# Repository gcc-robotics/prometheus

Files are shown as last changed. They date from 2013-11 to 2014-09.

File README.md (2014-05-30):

Prometheus
==========

The Prometheus is a robotic arm project created by the [Glendale Community College Robotics Academy][0].

This repository contains the software, electronics schematics, and mechanical models for the Prometheus robotic arm.

Prometheus Startup Procedure
----------------------------
1. Make sure the hardware and electronics are connected correctly.
2. Power up the Raspberry Pi, Router, and only the 5V rail for the electronics board.
   __Do not turn on the 12V rail! This will cause the arm to move to it's default position which could cause rapid movement and the arm could impact something.__
3. Connect a computer, tablet, or phone to the router either by ethernet or WiFi. The WiFi info is on the router.
4. Now open a browser and go to:

		10.33.0.2
	
	 This will open up the Prometheus Remote Control Interface.

5. Now click __Settings__ in the top right corner of the screen and then turn on the __Command Console__. Click the __X__ in the top right corner to close the Settings Screen.

6. Now go to the bottom of the page and tun the following commands:

        getJointLimits 0
        getJointLimits 1
        getJointLimits 2
        getJointLimits 3
        getJointLimits 4

7. Now use the setpoint sliders to set all the joint to a position where the arm will not hit anything when it is turned on.

8. Finaly, once you are confident that the setpoints are good turn on the 12V rail. The arm will now move to the setpoints you specified and you will be able to control it using the remote control interface.

Sistine Chapel - Arduino Software
---------------------------------

The __sistineChapel__ subdirectory contains the Arduino software for controlling the Prometheus.

### Setup

To compile and upload to the Arduino use the free [Arduino IDE][1]. Once you have installed the IDE the following steps will let you upload and test the Arduino software.

* Start Arduino IDE
* Select Tools -> Board -> Arduino Pro Mini 5V W/ ATmega328
* Open [sistineChapel/sistineChapel.ino][2] 
* File -> Upload

Narthex - Raspberry Pi Software
-------------------------------

The __narthex__ subdirectory contains the software to be run on the Raspberry Pi. 

The software runs a simple web server to serve a static web page with controls for Prometheus enabling remote control. The python code transfers commands between the Arduino and the Javascript running in the open webpage.

[0]: http://www.robotics.glendale.edu
[1]: http://arduino.cc/en/Main/Software
[2]: https://github.com/gcc-robotics/prometheus/blob/master/sistineChapel/sistineChapel.ino

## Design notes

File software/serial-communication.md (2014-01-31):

Serial Communication Documentation
==================================

This is a list of commands that the Arduino will accept over serial. The commands should be sent as strings with a newline character at the end.

Status Reporting
----------------

The Arduino sends the current angle for every joint in every loop iteration with the following syntax:

armStatus [joint0angle] [joint1angle] [joint2angle] [joint3angle] [joint4angle] [joint0error] [joint1error] [joint2error] [joint3error] [joint4error]

* joint[0-4]angle
  Float between 0.0 and 360.0
* joint[0-4]error
  Float between 0.0 and 360.0

Commands
--------

* setJointAngle [jointNumber] [angle]
* getJointAngle [jointNumber]
* getJointLimits [jointNumber]
* setJointGains [jointNumber] [PGain] [IGain] [DGain]
* getJointGains [jointNumber]
* getjointError [jointNumber]

### setJointAngle [jointNumber] [angle]

#### Description

The Arduino sets the selected joint to the provided angle.

#### Params

* jointNumber
  Integer between 0 and 4
* angle
  Integer between 0 and 359

#### Response

jointSetPoint [jointNumber] [angle]

* jointNumber
  Integer between 0 and 4
* angle
  Integer between 0 and 359

### getJointAngle [jointNumber]

#### Description

The Arduino gets the current encoder angle for the provided joint and sends it back in the response.

#### Params

* jointNumber
  Integer between 0 and 4

#### Response

jointAngle [jointNumber] [angle]

* jointNumber
  Integer between 0 and 4
* angle
  Integer between 0 and 359

### getJointLimits [jointNumber]

#### Description

The Arduino gets the current encoder angle for the provided joint and sends it back in the response.

#### Params

* jointNumber
  Integer between 0 and 4

#### Response

jointLimits [jointNumber] [min] [max]

* jointNumber
  Integer between 0 and 4
* min
  Integer between 0 and 359
* max
  Integer between 0 and 359

### getJointGains [jointNumber]

#### Description

The Arduino will return the PID gains for the current joint.

#### Params

* jointNumber
  Integer between 0 and 4

#### Response

jointGains [jointNumber] [PGain] [IGain] [DGain]

* jointNumber
  Integer between 0 and 4
* PGain
  Float between 0.0 and 5.0
* IGain
  Float between 0.0 and 5.0
* DGain
  Float between 0.0 and 5.0

### setJointGains [jointNumber] [PGain] [IGain] [DGain]

#### Description

The Arduino will set the provided values as the joint PID gains.

#### Params

* jointNumber
  Integer between 0 and 4
* PGain
  Float between 0.0 and 5.0 and must always be 2 digits after the decimal place
* IGain
  Float between 0.0 and 5.0 and must always be 2 digits after the decimal place
* DGain
  Float between 0.0 and 5.0 and must always be 2 digits after the decimal place

#### Response

No response

### getJointError [jointNumber]

#### Description

The Arduino will return the current angle error for the provided joint.

#### Params

* jointNumber
  Integer between 0 and 4

#### Response

jointError [jointNumber] [error]

* jointNumber
  Integer between 0 and 4
* error
  Float between -180.0 and 180.0

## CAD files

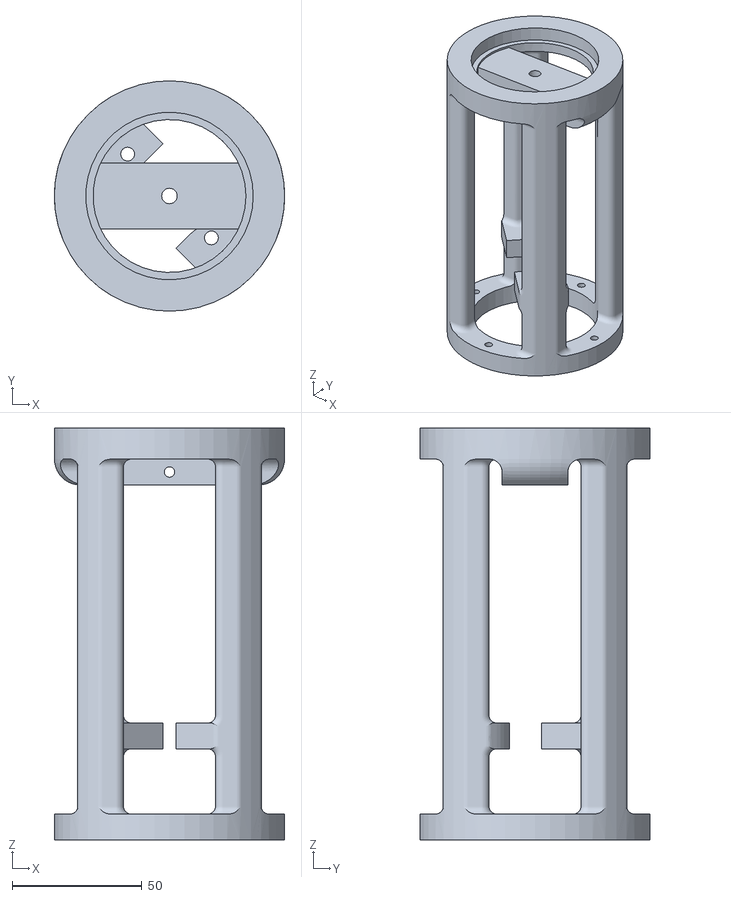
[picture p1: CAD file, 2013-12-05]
mechanical/forearm-front.stl
88.9 x 88.9 x 159.0

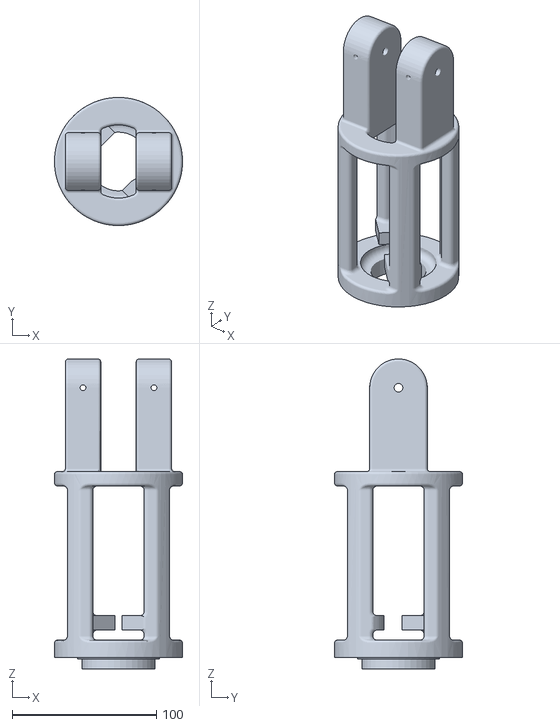
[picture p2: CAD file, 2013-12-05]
mechanical/forearm-back.stl
88.9 x 88.9 x 215.1

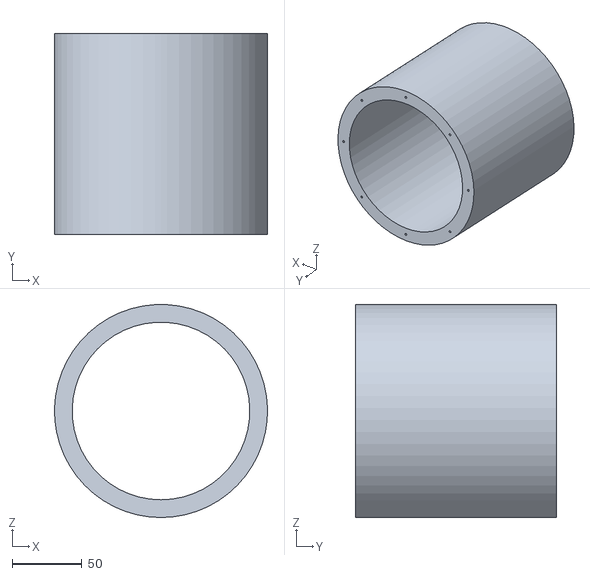
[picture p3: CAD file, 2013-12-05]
mechanical/base.stl
152.3 x 143.6 x 152.4

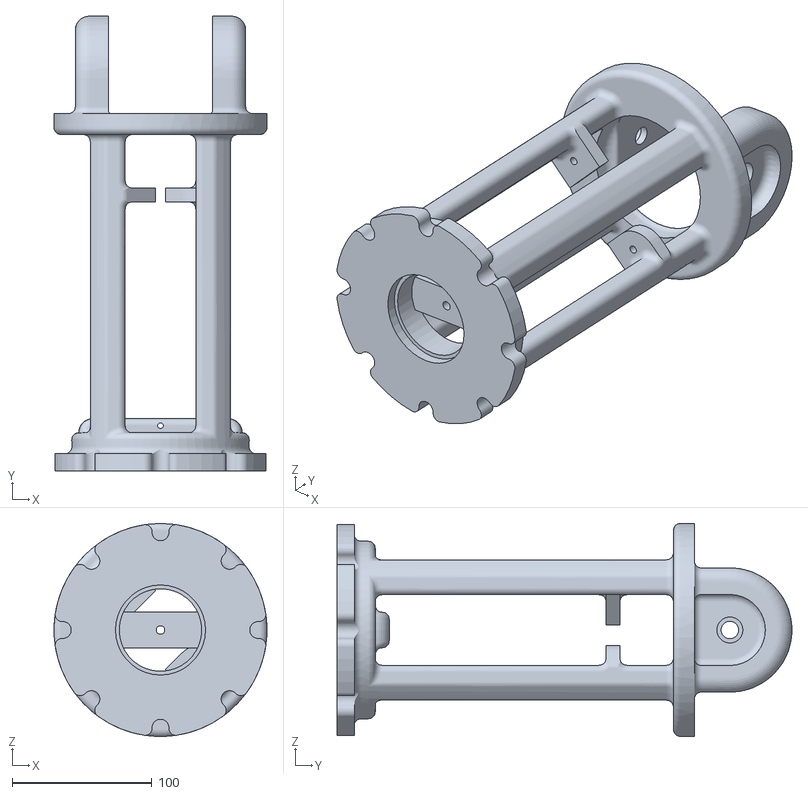
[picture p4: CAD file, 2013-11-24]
mechanical/torso.stl
152.4 x 325.5 x 152.4

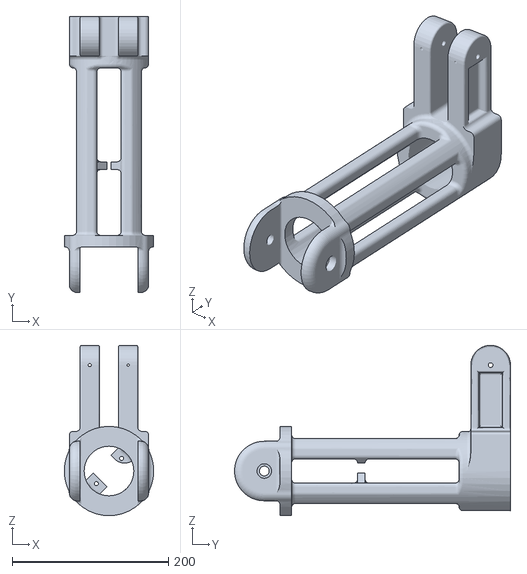
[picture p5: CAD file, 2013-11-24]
mechanical/humerus.stl
114.3 x 353.0 x 217.9

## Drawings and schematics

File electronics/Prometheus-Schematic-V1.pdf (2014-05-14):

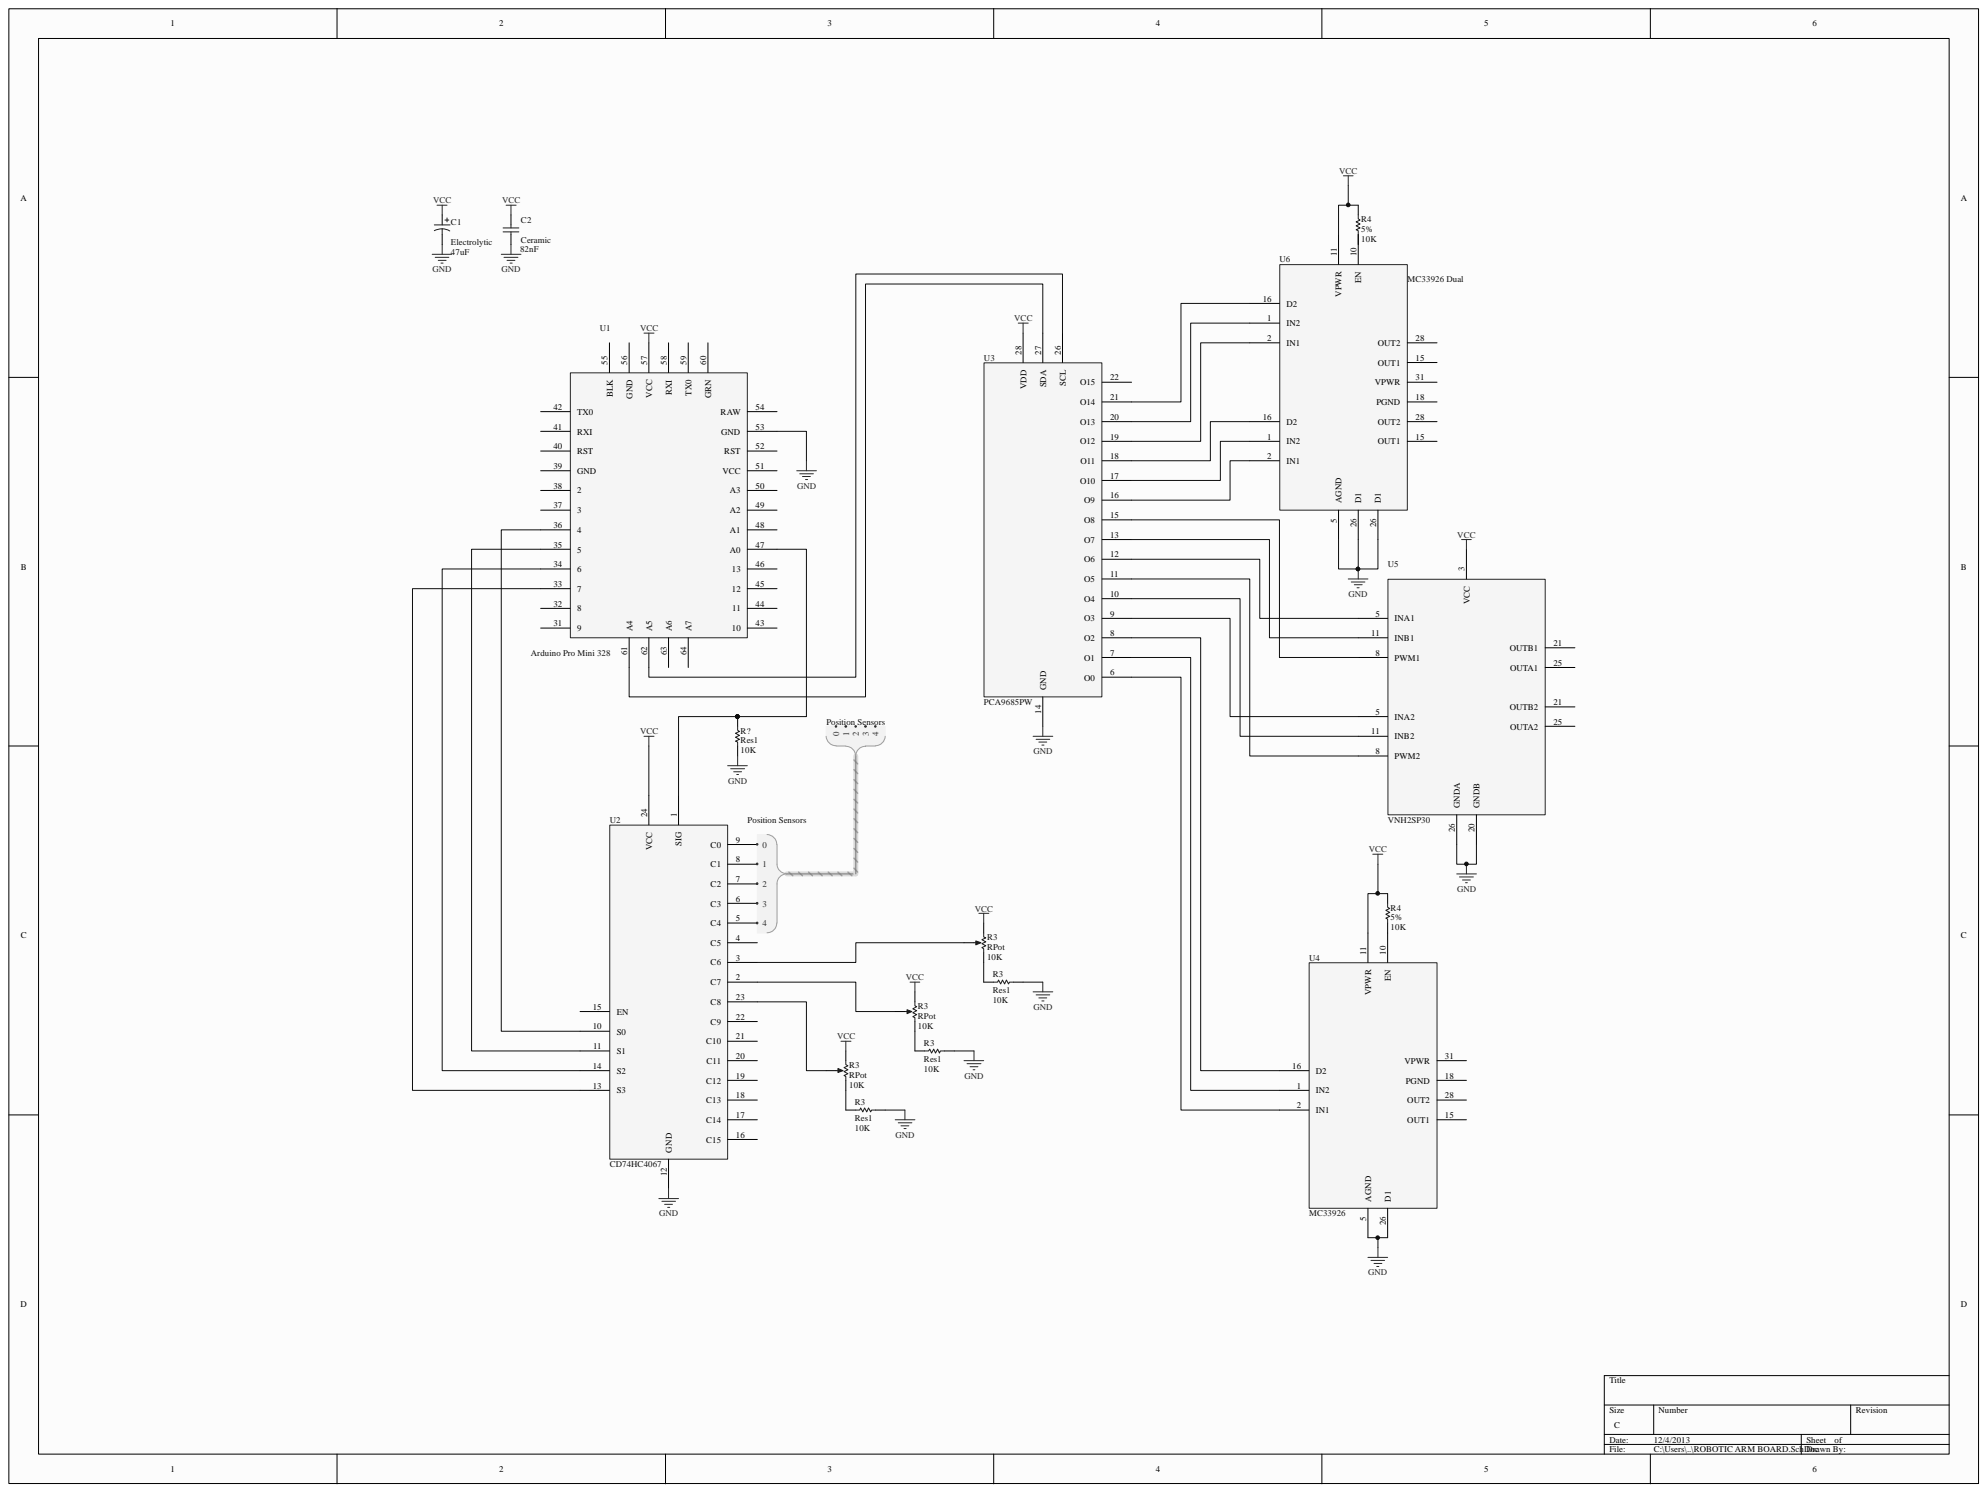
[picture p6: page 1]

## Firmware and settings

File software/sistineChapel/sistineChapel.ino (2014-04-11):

#include <Wire.h>
#include <Adafruit_PWMServoDriver.h>

#include "robotArm.h"
#include "debugger.h"
#include "commandProcessor.h"

// This isn't the greatest placement
RobotArm arm = RobotArm();
Debugger debug = Debugger();
CommandProcessor commandProcessor = CommandProcessor();

// Enable or disable debugger
boolean runDebugger = false;

void setup() 
{ 
	// Start serial communication at the specified baud rate
	Serial.begin(115200); // 115200 is max

	// Set timeout for serial read functions to 10ms
	// Use 10ms instead of the default 1000 so that the
	// arm controls work better while the debugger is active
	Serial.setTimeout(50);

	// Setup the arm
	arm.setup();
	commandProcessor.setup(&arm);
	debug.setup(arm.getMultiplexer(), arm.getMotorController(), &arm);

	// Interrupt
	attachInterrupt(arm.interruptNumber, globalInterruptResponder, CHANGE);

	// Set a random setPoint for the elbow
	//randomSeed(analogRead(A3));
	//arm.waist(random(0, 360));
}

void loop() 
{
	arm.loop();
	commandProcessor.loop();

	if(runDebugger)
	{
		debug.loop();
	}

	/*int pin = 1;
	Serial.println(analogRead(pin));*/
}

void globalInterruptResponder()
{
	arm.interruptResponder();
}

float stringToFloat(String input)
{
	int dotPosition = input.indexOf(".");
	int decimalPlaces = input.length() - (dotPosition + 1);

	int first = input.substring(0, dotPosition).toInt();
	int second = input.substring(dotPosition + 1).toInt();

	return first + (second / pow(10, decimalPlaces));
}

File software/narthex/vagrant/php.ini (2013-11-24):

[PHP]

;;;;;;;;;;;;;;;;;;;
; About php.ini   ;
;;;;;;;;;;;;;;;;;;;
; PHP's initialization file, generally called php.ini, is responsible for
; configuring many of the aspects of PHP's behavior.

; PHP attempts to find and load this configuration from a number of locations.
; The following is a summary of its search order:
; 1. SAPI module specific location.
; 2. The PHPRC environment variable. (As of PHP 5.2.0)
; 3. A number of predefined registry keys on Windows (As of PHP 5.2.0)
; 4. Current working directory (except CLI)
; 5. The web server's directory (for SAPI modules), or directory of PHP
; (otherwise in Windows)
; 6. The directory from the --with-config-file-path compile time option, or the
; Windows directory (C:\windows or C:\winnt)
; See the PHP docs for more specific information.
; http://php.net/configuration.file

; The syntax of the file is extremely simple.  Whitespace and Lines
; beginning with a semicolon are silently ignored (as you probably guessed).
; Section headers (e.g. [Foo]) are also silently ignored, even though
; they might mean something in the future.

; Directives following the section heading [PATH=/www/mysite] only
; apply to PHP files in the /www/mysite directory.  Directives
; following the section heading [HOST=www.example.com] only apply to
; PHP files served from www.example.com.  Directives set in these
; special sections cannot be overridden by user-defined INI files or
; at runtime. Currently, [PATH=] and [HOST=] sections only work under
; CGI/FastCGI.
; http://php.net/ini.sections

; Directives are specified using the following syntax:
; directive = value
; Directive names are *case sensitive* - foo=bar is different from FOO=bar.
; Directives are variables used to configure PHP or PHP extensions.
; There is no name validation.  If PHP can't find an expected
; directive because it is not set or is mistyped, a default value will be used.

; The value can be a string, a number, a PHP constant (e.g. E_ALL or M_PI), one
; of the INI constants (On, Off, True, False, Yes, No and None) or an expression
; (e.g. E_ALL & ~E_NOTICE), a quoted string ("bar"), or a reference to a
; previously set variable or directive (e.g. ${foo})

; Expressions in the INI file are limited to bitwise operators and parentheses:
; |  bitwise OR
; ^  bitwise XOR
; &  bitwise AND
; ~  bitwise NOT
; !  boolean NOT

; Boolean flags can be turned on using the values 1, On, True or Yes.
; They can be turned off using the values 0, Off, False or No.

; An empty string can be denoted by simply not writing anything after the equal
; sign, or by using the None keyword:

;  foo =         ; sets foo to an empty string
;  foo = None    ; sets foo to an empty string
;  foo = "None"  ; sets foo to the string 'None'

; If you use constants in your value, and these constants belong to a
; dynamically loaded extension (either a PHP extension or a Zend extension),
; you may only use these constants *after* the line that loads the extension.

;;;;;;;;;;;;;;;;;;;
; About this file ;
;;;;;;;;;;;;;;;;;;;
; PHP comes packaged with two INI files. One that is recommended to be used
; in production environments and one that is recommended to be used in
; development environments.

; php.ini-production contains settings which hold security, performance and
; best practices at its core. But please be aware, these settings may break
; compatibility with older or less security conscience applications. We
; recommending using the production ini in production and testing environments.

; php.ini-development is very similar to its production variant, except it's
; much more verbose when it comes to errors. We recommending using the
; development version only in development environments as errors shown to
; application users can inadvertently leak otherwise secure information.

;;;;;;;;;;;;;;;;;;;
; Quick Reference ;
;;;;;;;;;;;;;;;;;;;
; The following are all the settings which are different in either the production
; or development versions of the INIs with respect to PHP's default behavior.
; Please see the actual settings later in the document for more details as to why
; we recommend these changes in PHP's behavior.

; allow_call_time_pass_reference
;   Default Value: On
;   Development Value: Off
;   Production Value: Off

; display_errors
;   Default Value: On
;   Development Value: On
;   Production Value: Off

; display_startup_errors
;   Default Value: Off
;   Development Value: On
;   Production Value: Off

; error_reporting
;   Default Value: E_ALL & ~E_NOTICE
;   Development Value: E_ALL | E_STRICT
;   Production Value: E_ALL & ~E_DEPRECATED

; html_errors
;   Default Value: On
;   Development Value: On
;   Production value: Off

; log_errors
;   Default Value: Off
;   Development Value: On
;   Production Value: On

; magic_quotes_gpc
;   Default Value: On
;   Development Value: Off
;   Production Value: Off
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

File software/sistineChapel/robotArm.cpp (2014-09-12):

#import <Arduino.h>
#include <math.h>
#include "robotArm.h"

RobotArm::RobotArm()
{
	/*	Joint numbers:
		0: waist
		1: shoulder
		2: elbow
		3: wrist
		4: hand
	*/
}

void RobotArm::setup()
{
	const int numMotors = 5;
	this->openClawPin = 9;
	this->closeClawPin = 8;

	pinMode(this->openClawPin, OUTPUT);
	pinMode(this->closeClawPin, OUTPUT);
	
	// Motor numbers
	this->motorNumber[0] = 0;
	this->motorNumber[1] = 1;
	this->motorNumber[2] = 2;
	this->motorNumber[3] = 3;
	this->motorNumber[4] = 4;

	// Encoder numbers
	this->encoderNumber[0] = 0;
	this->encoderNumber[1] = 1;
	this->encoderNumber[2] = 2;
	this->encoderNumber[3] = 3;
	this->encoderNumber[4] = 4;

	// Encoder offsets
	this->encoderOffset[0] = 135;
	this->encoderOffset[1] = 34.0;
	this->encoderOffset[2] = 292.0;
	this->encoderOffset[3] = 113.0;
	this->encoderOffset[4] = 0;

	// Interrupt 
	this->emergencyState = false;
	this->interruptNumber = 1;
	this->interruptPinNumber = 3;

	pinMode(this->interruptPinNumber, INPUT);

	// Create and setup member objects
	this->mux = Multiplexer();
	this->motor = MotorController();
	this->motorSpeed = PIMotorSpeed();

	this->motor.setup();
}

void RobotArm::interruptResponder()
{
	// Get the state of the interrupt pin
	this->emergencyState = digitalRead(this->interruptPinNumber);
}

Multiplexer* RobotArm::getMultiplexer()
{
	return &(this->mux);
}

MotorController* RobotArm::getMotorController()
{
	return &(this->motor);
}

PIMotorSpeed* RobotArm::getPIMotorSpeed()
{
	return &(this->motorSpeed);
}

bool RobotArm::moveJointToSetPoint(int jointNumber)
{
	// Get the current angle
	float currentAngle = this->getJointAngle(jointNumber);

	// Serial.print("Moving Joint: ");
	// Serial.print(jointNumber);

	// Serial.print(", Curent angle: ");
	// Serial.print(currentAngle);

	// Get the motor speed
	int motorSpeed = this->motorSpeed.calculate(jointNumber, currentAngle);

	// Serial.print(", Calculated motor speed: ");
	// Serial.println(motorSpeed);

	this->motor.speed(jointNumber, motorSpeed);
}

void RobotArm::setJointAngle(int jointNumber, float angle)
{
	this->motorSpeed.setSetPoint(jointNumber, angle);
}

float RobotArm::getJointAngle(int jointNumber)
{
	float encoderOutput = this->mux.readEncoder(this->encoderNumber[jointNumber]) - encoderOffset[jointNumber];
	
	while(encoderOutput < 0)
	{
		encoderOutput += 360;
	}
	
	return encoderOutput;
}

float RobotArm::getJointMinimum(int jointNumber)
{
	return this->motorSpeed.getJointMin(jointNumber);
}

float RobotArm::getJointMaximum(int jointNumber)
{
	return this->motorSpeed.getJointMax(jointNumber);
}

void RobotArm::openClaw()
{
	digitalWrite(this->openClawPin, HIGH);
	digitalWrite(this->closeClawPin, LOW);
}

void RobotArm::closeClaw()
{
	digitalWrite(this->openClawPin, LOW);
	digitalWrite(this->closeClawPin, HIGH);
}

void RobotArm::brakeClaw()
{
	digitalWrite(this->openClawPin, LOW);
	digitalWrite(this->closeClawPin, LOW);
}

void RobotArm::waist(float targetAngle)
{
	this->setJointAngle(0, targetAngle);
}

void RobotArm::shoulder(float targetAngle)
{
	this->setJointAngle(1, targetAngle);
}

void RobotArm::elbow(float targetAngle)
{
	this->setJointAngle(2, targetAngle);
}

void RobotArm::wrist(float targetAngle)
{
	this->setJointAngle(3, targetAngle);
}

void RobotArm::hand(float targetAngle)
{
	this->setJointAngle(4, targetAngle);
}

void RobotArm::loop()
{
	if(!this->emergencyState)
	{
		// Waist
		this->moveJointToSetPoint(0);

		// Shoulder
		this->moveJointToSetPoint(1);

		// Elbow
		this->moveJointToSetPoint(2);

		// Wrist
		this->moveJointToSetPoint(3);

		// Hand
		this->moveJointToSetPoint(4);
	}
	else
	{
		// Emergency State is Active!
		// Coast for now, brake when we have fuses
		for(int i = 0; i < 5; i++)
		{
			this->motor.coast(this->motorNumber[i]);
		}
	}
}

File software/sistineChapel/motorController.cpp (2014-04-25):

#import <Arduino.h>
#include "motorController.h"

MotorController::MotorController()
{
	// Setup pwm
	this->pwm = Adafruit_PWMServoDriver();
}

void MotorController::setup()
{
	this->pwm.begin();

	// Set the frequency for the pwm driver
	this->pwm.setPWMFreq(60);
}

void MotorController::setPwm(int motorNum, float dutyCycle)
{
	// Clamp duty cycle between 0 to 100
	if(dutyCycle > 100)
	{
		dutyCycle = 100;
	}

	if(dutyCycle < 0)
	{
		dutyCycle = 0;
	}

	// selects the third pin on the pwm driver
	int pin = 3 * motorNum + 2;

	//calculates the integer value for the desired duty cycle
	float rate = dutyCycle * 40.95;

	this->pwm.setPWM(pin, 0, int(rate));
}

void MotorController::forward(int motorNum)
{
	int pin = 3 * motorNum;	//selects the first pin on the pwm driver

	this->pwm.setPWM(pin, 4095, 0);	//Sets the INA pin of the motor to LOW
	this->pwm.setPWM(pin + 1, 0, 4095);	//Sets the INB pin of the motor to High
}

void MotorController::reverse(int motorNum)
{
	int pin = 3 * motorNum;	//selects the first pin on the pwm driver

	this->pwm.setPWM(pin, 0, 4095);	//Sets the INA pin of the motor to HIGH
	this->pwm.setPWM(pin + 1, 4095, 0);	//Sets the INB pin of the motor to LOW
}

void MotorController::speed(int motorNumber, int speed)
{
	// Temporary speed limit for elbow needs fixing..........................................................................................................................................................................
	/*if(motorNumber == 3)
	{
		speed = speed / 4;
	}*/

	if(speed > 0)
	{
		this->forward(motorNumber);
		this->setPwm(motorNumber, speed);
	}
	else if(speed < 0)
	{
		speed *= -1;

		this->reverse(motorNumber);
		this->setPwm(motorNumber, speed);
	}
	else
	{
		this->setPwm(motorNumber, 0);
	}
}

void MotorController::coast(int motorNumber)
{
	int pin = 3 * motorNumber; //selects the first pin on the pwm driver

	this->pwm.setPWM(pin, 4095, 0); //Sets the INA pin of the motor to Low
	this->pwm.setPWM(pin + 1, 4095, 0); //Sets the INB pin of the motor to Low
}

void MotorController::brake(int motorNum)
{
	int pin = 3 * motorNum;	//selects the first pin on the pwm driver
	
	this->pwm.setPWM(pin, 0, 4095);	//Sets the INA pin of the motor to High
	this->pwm.setPWM(pin + 1, 0, 4095);	//Sets the INB pin of the motor to High
}

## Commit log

2013-10-12 Inital commit of arm code.
2013-10-15 Remove everything except the motor control code to test the Motor Controllers.
2013-10-15 Added debug & Diagnostics
    * Added file 'diagnostics.ino' which contains all debug functions
    * Added file 'motorController.ino' which contains all functions for
    controlling motors and applying PWM.
2013-10-19 Create a Debugger class to replace the code previously in diagnostics.ino This version of the code does not yet compile because it calls functions defined out of scope. This will be resolved once Enc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
    [debugger.cpp, sistineChapel.ino]
2013-10-19 Replace analogSignalToEncoderAngle() with Multiplexer::readEncoder()
    [debugger.cpp, multiplexer.cpp, sistineChapel.ino]
2013-10-22 added motorcontroller class
2013-10-22 updated motorcontroller class, including new methods
2013-10-22 Integrate MotorController class with rest of the code.
2013-10-23 Make motors 0-indexed instead of 1-indexed
2013-10-23 Add RobotArm class to encapsulate the subclasses and make controlling the arm easier. Disable the debugger until it is updated for the RobotArm class.
2013-10-24 Updated the RobotArm class to use PID controls.
2013-10-26 Add PID tunning to debugger class. Potentionmeter read to Mux class. SetPidGain to RobotArm class.
2013-10-29 Fix issues with PID debugger.
    [debugger.cpp, motorController.cpp, robotArm.cpp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]
2013-10-31 Update robot arm and debugger to controll two joints at once.
2013-11-05 First version of motor speed boost code for low speed motor operation
    Adds motor speed boost code in the RobotArm class for low speed motor
    operation. Currently has a bug that causes a random long term boost
    after and random period of time.
    [robotArm.cpp, sistineChapel.ino]
2013-11-07 Fix bug in motor speed boost code caused by time overflow.
    [robotArm.cpp, sistineChapel.ino]
2013-11-20 Add link to WebGL STL rendering to the readme
2013-11-21 Add command processor for serial commands to arduino code.
2013-11-24 Start work on WebGL rendering of the arm.
    [humerus.stl, torso.stl]
2013-11-24 Continue work on WebGL rendering of the arm.
2013-11-24 Add second light, add ground plane, and enable camera rotation.
2013-12-05 Fix bugs with serial communication code.
    [commandProcessor.cpp, robotArm.cpp, server.py]
2013-12-05 Add additional STLs to WebGL rendering of Prometheus.
    [base.stl, forearm-back.stl, forearm-front.stl]
2013-12-06 Fix communication issues on python and js end.
    [server.py]
2013-12-07 Fix issues with serial communication. Add serial communication testing class.
    [commandProcessor.cpp, server.py]
2014-01-02 Remove broken code
    Remove PID and boost code so that the RobotArm class can control
    5 motors at the same time.
    [debugger.cpp, robotArm.cpp, sistineChapel.ino]
2014-01-03 Work on test-serial.py to try and fix the serial communication
    [sistineChapel.ino]
2014-01-14 Started on Proportional Motor Speed class
2014-01-17 Fixed the RobotArm class and implemented PMotorSpeed class into RobotArm class
    [PMotorSpeed.cpp, robotArm.cpp]
2014-01-30 Updated CommandProcessor class to print angle errors with current angle.
    [commandProcessor.cpp, sistineChapel.ino]
2014-02-02 Fix issues with socket server on dispatching events.
    [PrometheusSerial.py, server.py]
2014-02-06 Modified arm status to report slower to match the python
2014-02-12 Rework the PI implementation to resolve the previous issues.
    [PIMotorSpeed.cpp, PMotorSpeed.cpp, multiplexer.cpp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]
2014-02-14 Add PID tuning capability to the remote control interface.
2014-02-14 Update socket server URL.
2014-02-28 Add interupt code
    Add interupt code that coasts the motors when the interupt is high
    and starts moving them again when it returns to low. Once the fuses
    are added to the electronics board we should probably brake the
    motors instead to stop the arm quicker.
2014-03-07 Change directory structure so that electronics and mechanical can be added.
    [base.stl, forearm-back.stl, forearm-front.stl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]
2014-03-26 Implemented PIDMotorSpeed in PIMotorSpeed class and fixed angleError function and fixed for encoder offsets.
    [PIMotorSpeed.cpp, PMotorSpeed.cpp, commandProcessor.cpp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]
2014-03-28 Implemented claw codes and modified commandprocessor to support claw controls
2014-03-28 Add claw control to the remote control interface.
2014-03-28 deleted PIDMotorSpeed files -> PID is implemented inside PIMotorSpeed
2014-03-28 Work to bring arm to functional status for CSUN event.
2014-03-29 Working version if encoder offsets are turned off.
2014-03-29 Fix encoder offsets.
2014-04-04 Update encoder offsets and limits for more joints
2014-04-11 Continue work on seting up joints.
2014-04-11 Fix bug in floatToString
    [commandProcessor.cpp]
2014-04-11 Continue work on getting the arm functional.
2014-04-25 Fixed the offsets and limits and all the joints work now.
    [PMotorSpeed.cpp, commandProcessor.cpp, motorController.cpp]
2014-04-26 Readjusted the encoder offsets
2014-05-14 Add the schematics for the control board.
    [Prometheus-Schematic-V1.SchDoc]
2014-05-16 Add STLs for several of the 3D printed parts.
    [base.stl, forearm-back.stl, forearm-front.stl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]
2014-05-30 Update Narthex PrometheusSerial to automaticaly retry serial communication after 10 seconds if it fails to connect.
    [PrometheusSerial.py]
2014-05-30 Fix issues with narthex auto-start
    [server.py]
